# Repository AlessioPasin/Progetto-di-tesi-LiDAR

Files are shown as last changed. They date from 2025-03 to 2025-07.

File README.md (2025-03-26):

# Progetto di tesi: **Scheda per sensore LiDAR**

## Obiettivo:

Il seguente progetto riguarda una scheda per la gestione di due periferiche esterne: un laser ed un fotoricevitore.
L'obiettivo finale con la scheda è quello di realizzare un sensore LiDAR. Tale sensore viene utilizzato in diversi campi per misurare quella che è la distanza degli oggetti circostanti. Ne esistono di diverse tipologie e che sfruttano diversi principi fisici.

In questa applicazione viene utilizzato il **ToF** [*Time of Filght*], ossia il tempo che impiega il fascio laser per viaggare dalla sorgente all'oggetto e per poi tornare nuovamente alla fonte.

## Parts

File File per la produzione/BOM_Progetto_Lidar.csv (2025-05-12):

Source: | D:\Documenti_A\Università\Corsi\Tesi\Progetto Kicad Lidar\Progetto Lidar.kicad_sch
Date: | 12/05/2025 09:19:33
Tool: | Eeschema (6.0.10)
Generator: | C:\Program Files\KiCad\6.0\bin\scripting\plugins/bom_csv_grouped_by_value.py
Component Count: | 44
Individual Components:
Item | Qty | Reference(s) | Value | LibPart | Footprint | Datasheet | Datasheet_1 | Dettagli | Footprint_1 | Height | Manufacturer_Name | Manufacturer_Part_Number | Modello | Mouser Part Number | Mouser Price/Stock | Reference_1 | Value_1
 |  | C1 | 0.1uF | Device:C | Capacitor_SMD:C_0805_2012Metric | ~
 |  | C2 | 1uF | Device:C | Capacitor_SMD:C_0805_2012Metric | ~
 |  | C3 | 100nF | Device:C | Capacitor_SMD:C_0805_2012Metric | ~
 |  | C4 | 1uF | Device:C | Capacitor_SMD:C_0805_2012Metric | ~ |  | Ceramico con ESR: 100 mOhm max
 |  | C5 | 100nF | Device:C | Capacitor_SMD:C_0805_2012Metric | ~
 |  | C6 | 100nF | Device:C | Capacitor_SMD:C_0805_2012Metric | ~
 |  | C7 | 100nF | Device:C | Capacitor_SMD:C_0805_2012Metric | ~
 |  | C8 | 1nF | Device:C | Capacitor_SMD:C_0805_2012Metric | ~
 |  | C9 | 1nF | Device:C | Capacitor_SMD:C_0805_2012Metric | ~
 |  | C10 | 50pF | Device:C | Capacitor_SMD:C_0805_2012Metric | ~
 |  | C11 | 1nF | Device:C | Capacitor_SMD:C_0805_2012Metric | ~
 |  | C12 | 1nF | Device:C | Capacitor_SMD:C_0805_2012Metric | ~
 |  | D1 | 5V | Device:LED | LED_SMD:LED_0805_2012Metric | https://www.mouser.it/ProductDetail/ROHM-Semiconductor/SML-211UTT86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
 |  | D2 | 3V3 | Device:LED | LED_SMD:LED_0805_2012Metric | ~
 |  | D3 | D_Shockley | Device:D_Schottky | Libreria_componenti_footprint:RB511VM30TE17 | Datasheet/rb511vm-30te-17-e.pdf |  |  |  |  |  |  | RB511VM-30TE-17
 |  | IC_0 | Arduino_Due_Shield | arduino-library:Arduino_Due_Shield | arduino-library:Arduino_Due_Shield | https://docs.arduino.cc/hardware/due
 |  | IC_1 | TDC7200PW | Libreria_componenti:TDC7200PW | Libreria_componenti_footprint:SOP65P640X120-14N | Datasheet/tdc7200.pdf | http://www.ti.com/lit/ds/symlink/tdc7200.pdf |  | SOP65P640X120-14N | 1.2 | Texas Instruments | TDC7200PW |  | 595-TDC7200PW | https://www.mouser.co.uk/ProductDetail/Texas-Instruments/TDC7200PW?qs=Q2snjRlG%2FBIHkOu3cFqg1g%3D%3D | IC | TDC7200PW
 |  | IC_2 | SiT2024BA-S2-33E-8.000000G | Libreria_componenti:SiT2024BA-S2-33E-8.000000G | Libreria_componenti_footprint:SOT95P280X145-5N | Datasheet/SiT2024B.pdf | https://www.mouser.it/datasheet/2/371/SiT2024B-datasheet-1110818.pdf |  | SOT95P280X145-5N | 1.45 | SiTime | SiT2024BA-S2-33E-8.000000G |  | 788-2024BA-S2-33E-8G | https://www.mouser.co.uk/ProductDetail/SiTime/SiT2024BA-S2-33E-8.000000G?qs=dMZC7um9hO%2FirfxPzzDefA%3D%3D | Y | SiT2024BA-S2-33E-8.000000G
 |  | IC_3 | SN74LVC1G125DCKR | Libreria_componenti:SN74LVC1G125DCKR | Libreria_componenti_footprint:SOT65P210X110-5N | Datasheet/sn74lvc1g125.pdf | https://datasheet.datasheetarchive.com/originals/distributors/Datasheets-302/24053.pdf |  | SOT65P210X110-5N | 1.1 | Texas Instruments | SN74LVC1G125DCKR |  | 595-SN74LVC1G125DCKR | https://www.mouser.co.uk/ProductDetail/Texas-Instruments/SN74LVC1G125DCKR?qs=dT9u2OTAaVUrYF5qV08%2Fhw%3D%3D | IC | SN74LVC1G125DCKR
 |  | IC_4 | LT1719IS6#TRPBF | Libreria_componenti:LT1719IS6#TRPBF | Libreria_componenti_footprint:SOT95P280X100-6N | Datasheet/LT1719IS6.pdf | https://www.analog.com/media/en/technical-documentation/data-sheets/1719fa.pdf |  | SOT95P280X100-6N | 1 | Analog Devices | LT1719IS6#TRPBF |  | 584-LT1719IS6#TRPBF | https://www.mouser.co.uk/ProductDetail/Analog-Devices/LT1719IS6TRPBF?qs=ytflclh7QUW7a8zSEpHCoA%3D%3D | IC | LT1719IS6#TRPBF
 |  | IC_5 | TLV74133PDBVR | Libreria_componenti:TLV74133PDBVR | Libreria_componenti_footprint:SOT95P280X145-5N | Datasheet/tlv741p.pdf |  |  |  | 1.45 | Texas Instruments | TLV74133PDBVR |  | 595-TLV74133PDBVR | https://www.mouser.co.uk/ProductDetail/Texas-Instruments/TLV74133PDBVR?qs=EU6FO9ffTwd%252Bkie4AO1Iww%3D%3D
 |  | J1 | CONN_LASER | Connector:Conn_Coaxial | Connector_Coaxial:SMA_Molex_73251-1153_EdgeMount_Horizontal | ~
 |  | J2 | CONN_RICEVITORE | Connector:Conn_Coaxial | Connector_Coaxial:SMA_Molex_73251-1153_EdgeMount_Horizontal | ~
 |  | J3 | Conn_02x18_Odd_Even | Connector_Generic:Conn_02x18_Odd_Even | Connector_PinSocket_2.54mm:PinSocket_2x18_P2.54mm_Vertical | ~
 |  | J4 | Conn_01x10 | Connector_Generic:Conn_01x10 | Connector_PinSocket_2.54mm:PinSocket_1x10_P2.54mm_Vertical | ~
 |  | J5 | Conn_01x08 | Connector_Generic:Conn_01x08 | Connector_PinSocket_2.54mm:PinSocket_1x08_P2.54mm_Vertical | ~
 |  | J6 | Conn_01x08 | Connector_Generic:Conn_01x08 | Connector_PinSocket_2.54mm:PinSocket_1x08_P2.54mm_Vertical | ~
 |  | J7 | Conn_01x08 | Connector_Generic:Conn_01x08 | Connector_PinSocket_2.54mm:PinSocket_1x08_P2.54mm_Vertical | ~
 |  | J8 | Conn_SPI | Connector_Generic:Conn_02x03_Odd_Even | Connector_PinSocket_2.54mm:PinSocket_2x03_P2.54mm_Vertical | ~
 |  | J9 | Conn_01x08 | Connector_Generic:Conn_01x08 | Connector_PinSocket_2.54mm:PinSocket_1x08_P2.54mm_Vertical | ~
 |  | J10 | Conn_01x08 | Connector_Generic:Conn_01x08 | Connector_PinSocket_2.54mm:PinSocket_1x08_P2.54mm_Vertical | ~
 |  | JP1 | REG_EN | Jumper:SolderJumper_2_Open | Jumper:SolderJumper-2_P1.3mm_Open_RoundedPad1.0x1.5mm | ~
 |  | JP2 | LDO_EN | Jumper:SolderJumper_3_Open | Jumper:SolderJumper-3_P1.3mm_Open_Pad1.0x1.5mm_NumberLabels | ~
 |  | JP3 | OSC_EN | Jumper:SolderJumper_2_Open | Jumper:SolderJumper-2_P1.3mm_Open_RoundedPad1.0x1.5mm | ~
 |  | R1 | 10k | Device:R | Resistor_SMD:R_0805_2012Metric | ~
 |  | R2 | 1k8 | Device:R | Resistor_SMD:R_0805_2012Metric | ~
 |  | R3 | 820 | Device:R | Resistor_SMD:R_0805_2012Metric | ~
 |  | R4 | 47 | Device:R | Resistor_SMD:R_0805_2012Metric | ~
 |  | R5 | 180 | Device:R | Resistor_SMD:R_0805_2012Metric | ~
 |  | R6 | 100 | Device:R | Resistor_SMD:R_0805_2012Metric | ~
 |  | R7 | 100 | Device:R | Resistor_SMD:R_0805_2012Metric | ~
 |  | R8 | 100 | Device:R | Resistor_SMD:R_0805_2012Metric | ~
 |  | R9 | 100 | Device:R | Resistor_SMD:R_0805_2012Metric | ~
 |  | R10 | 100 | Device:R | Resistor_SMD:R_0805_2012Metric | ~
Collated Components:
Item | Qty | Reference(s) | Value | LibPart | Footprint | Datasheet | Datasheet_1 | Dettagli | Footprint_1 | Height | Manufacturer_Name | Manufacturer_Part_Number | Modello | Mouser Part Number | Mouser Price/Stock | Reference_1 | Value_1
1 | 1 | C1 | 0.1uF | Device:C | Capacitor_SMD:C_0805_2012Metric | ~
2 | 2 | C2, C4 | 1uF | Device:C | Capacitor_SMD:C_0805_2012Metric | ~ |  | Ceramico con ESR: 100 mOhm max
3 | 4 | C3, C5, C6, C7 | 100nF | Device:C | Capacitor_SMD:C_0805_2012Metric | ~
4 | 4 | C8, C9, C11, C12 | 1nF | Device:C | Capacitor_SMD:C_0805_2012Metric | ~
5 | 1 | C10 | 50pF | Device:C | Capacitor_SMD:C_0805_2012Metric | ~
6 | 1 | D1 | 5V | Device:LED | LED_SMD:LED_0805_2012Metric | https://www.mouser.it/ProductDetail/ROHM-Semiconductor/SML-211UTT86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
7 | 1 | D2 | 3V3 | Device:LED | LED_SMD:LED_0805_2012Metric | ~
8 | 1 | D3 | D_Shockley | Device:D_Schottky | Libreria_componenti_footprint:RB511VM30TE17 | Datasheet/rb511vm-30te-17-e.pdf |  |  |  |  |  |  | RB511VM-30TE-17
9 | 1 | IC_0 | Arduino_Due_Shield | arduino-library:Arduino_Due_Shield | arduino-library:Arduino_Due_Shield | https://docs.arduino.cc/hardware/due
10 | 1 | IC_1 | TDC7200PW | Libreria_componenti:TDC7200PW | Libreria_componenti_footprint:SOP65P640X120-14N | Datasheet/tdc7200.pdf | http://www.ti.com/lit/ds/symlink/tdc7200.pdf |  | SOP65P640X120-14N | 1.2 | Texas Instruments | TDC7200PW |  | 595-TDC7200PW | https://www.mouser.co.uk/ProductDetail/Texas-Instruments/TDC7200PW?qs=Q2snjRlG%2FBIHkOu3cFqg1g%3D%3D | IC | TDC7200PW
11 | 1 | IC_2 | SiT2024BA-S2-33E-8.000000G | Libreria_componenti:SiT2024BA-S2-33E-8.000000G | Libreria_componenti_footprint:SOT95P280X145-5N | Datasheet/SiT2024B.pdf | https://www.mouser.it/datasheet/2/371/SiT2024B-datasheet-1110818.pdf |  | SOT95P280X145-5N | 1.45 | SiTime | SiT2024BA-S2-33E-8.000000G |  | 788-2024BA-S2-33E-8G | https://www.mouser.co.uk/ProductDetail/SiTime/SiT2024BA-S2-33E-8.000000G?qs=dMZC7um9hO%2FirfxPzzDefA%3D%3D | Y | SiT2024BA-S2-33E-8.000000G
12 | 1 | IC_3 | SN74LVC1G125DCKR | Libreria_componenti:SN74LVC1G125DCKR | Libreria_componenti_footprint:SOT65P210X110-5N | Datasheet/sn74lvc1g125.pdf | https://datasheet.datasheetarchive.com/originals/distributors/Datasheets-302/24053.pdf |  | SOT65P210X110-5N | 1.1 | Texas Instruments | SN74LVC1G125DCKR |  | 595-SN74LVC1G125DCKR | https://www.mouser.co.uk/ProductDetail/Texas-Instruments/SN74LVC1G125DCKR?qs=dT9u2OTAaVUrYF5qV08%2Fhw%3D%3D | IC | SN74LVC1G125DCKR
13 | 1 | IC_4 | LT1719IS6#TRPBF | Libreria_componenti:LT1719IS6#TRPBF | Libreria_componenti_footprint:SOT95P280X100-6N | Datasheet/LT1719IS6.pdf | https://www.analog.com/media/en/technical-documentation/data-sheets/1719fa.pdf |  | SOT95P280X100-6N | 1 | Analog Devices | LT1719IS6#TRPBF |  | 584-LT1719IS6#TRPBF | https://www.mouser.co.uk/ProductDetail/Analog-Devices/LT1719IS6TRPBF?qs=ytflclh7QUW7a8zSEpHCoA%3D%3D | IC | LT1719IS6#TRPBF
14 | 1 | IC_5 | TLV74133PDBVR | Libreria_componenti:TLV74133PDBVR | Libreria_componenti_footprint:SOT95P280X145-5N | Datasheet/tlv741p.pdf |  |  |  | 1.45 | Texas Instruments | TLV74133PDBVR |  | 595-TLV74133PDBVR | https://www.mouser.co.uk/ProductDetail/Texas-Instruments/TLV74133PDBVR?qs=EU6FO9ffTwd%252Bkie4AO1Iww%3D%3D
15 | 1 | J1 | CONN_LASER | Connector:Conn_Coaxial | Connector_Coaxial:SMA_Molex_73251-1153_EdgeMount_Horizontal | ~
16 | 1 | J2 | CONN_RICEVITORE | Connector:Conn_Coaxial | Connector_Coaxial:SMA_Molex_73251-1153_EdgeMount_Horizontal | ~
17 | 1 | J3 | Conn_02x18_Odd_Even | Connector_Generic:Conn_02x18_Odd_Even | Connector_PinSocket_2.54mm:PinSocket_2x18_P2.54mm_Vertical | ~
18 | 1 | J4 | Conn_01x10 | Connector_Generic:Conn_01x10 | Connector_PinSocket_2.54mm:PinSocket_1x10_P2.54mm_Vertical | ~
19 | 5 | J5, J6, J7, J9, J10 | Conn_01x08 | Connector_Generic:Conn_01x08 | Connector_PinSocket_2.54mm:PinSocket_1x08_P2.54mm_Vertical | ~
20 | 1 | J8 | Conn_SPI | Connector_Generic:Conn_02x03_Odd_Even | Connector_PinSocket_2.54mm:PinSocket_2x03_P2.54mm_Vertical | ~
21 | 1 | JP1 | REG_EN | Jumper:SolderJumper_2_Open | Jumper:SolderJumper-2_P1.3mm_Open_RoundedPad1.0x1.5mm | ~
22 | 1 | JP2 | LDO_EN | Jumper:SolderJumper_3_Open | Jumper:SolderJumper-3_P1.3mm_Open_Pad1.0x1.5mm_NumberLabels | ~
23 | 1 | JP3 | OSC_EN | Jumper:SolderJumper_2_Open | Jumper:SolderJumper-2_P1.3mm_Open_RoundedPad1.0x1.5mm | ~
24 | 1 | R1 | 10k | Device:R | Resistor_SMD:R_0805_2012Metric | ~
25 | 1 | R2 | 1k8 | Device:R | Resistor_SMD:R_0805_2012Metric | ~
26 | 1 | R3 | 820 | Device:R | Resistor_SMD:R_0805_2012Metric | ~
27 | 1 | R4 | 47 | Device:R | Resistor_SMD:R_0805_2012Metric | ~
28 | 1 | R5 | 180 | Device:R | Resistor_SMD:R_0805_2012Metric | ~
29 | 5 | R6, R7, R8, R9, R10 | 100 | Device:R | Resistor_SMD:R_0805_2012Metric | ~

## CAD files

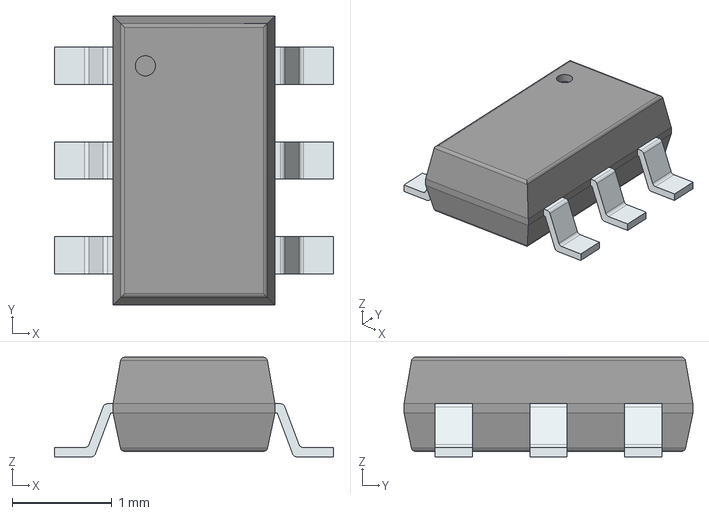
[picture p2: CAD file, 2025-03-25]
Componenti scaricati/LIB_LT1719IS6#TRPBF/3D/LT1719IS6#TRPBF.stp
2.80 x 2.90 x 1.00 mm
PinsArrayLR

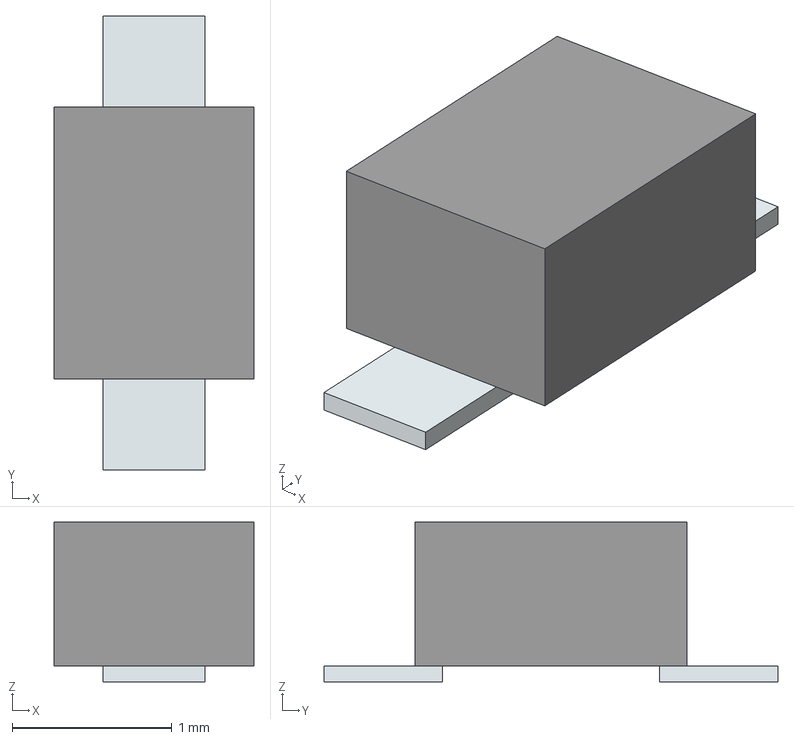
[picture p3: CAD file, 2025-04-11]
Componenti scaricati/LIB_RB511VM-30TE-17/3D/RB511VM-30TE-17.stp
1.25 x 2.84 x 1.00 mm
Pins

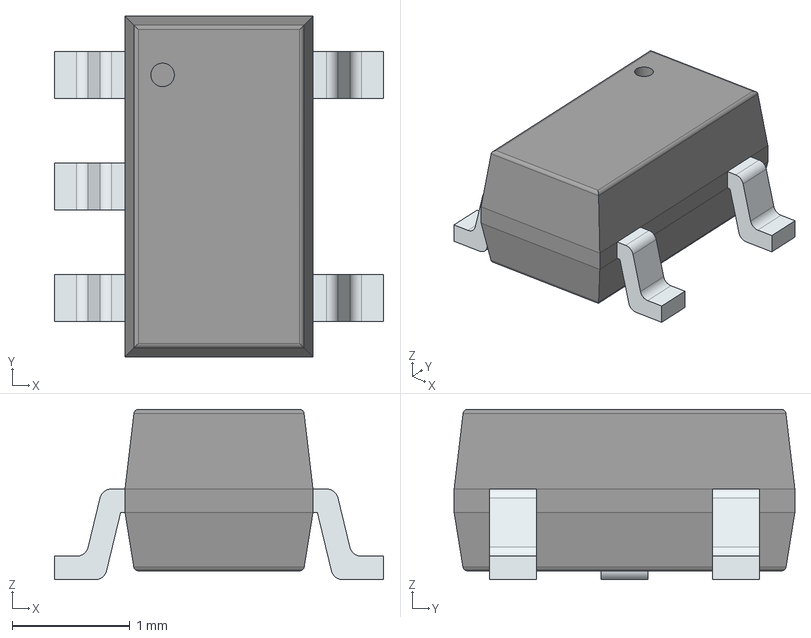
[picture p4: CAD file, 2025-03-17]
Componenti scaricati/LIB_SiT2024BA-S2-33E-8.000000G/3D/SiT2024BA-S2-33E-8.000000G.stp
2.80 x 2.90 x 1.45 mm
PinsArrayL
PinsArrayR

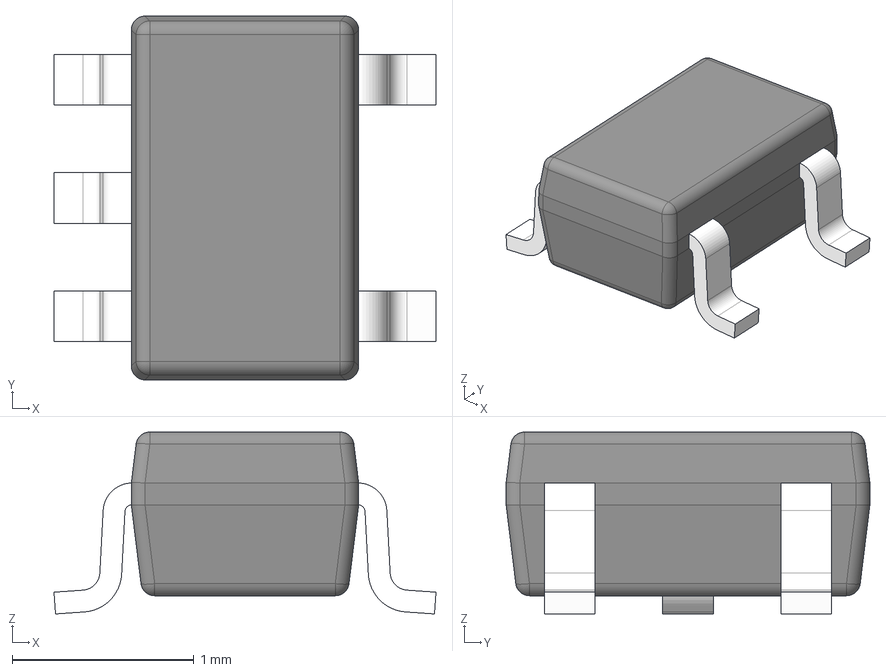
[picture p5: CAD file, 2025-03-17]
Componenti scaricati/LIB_SN74LVC1G125DCKR/3D/SN74LVC1G125DCKR.stp
2.10 x 2.00 x 1.00 mm
BODY-SOT
LEAD-SOT x 5
PIN1-ID

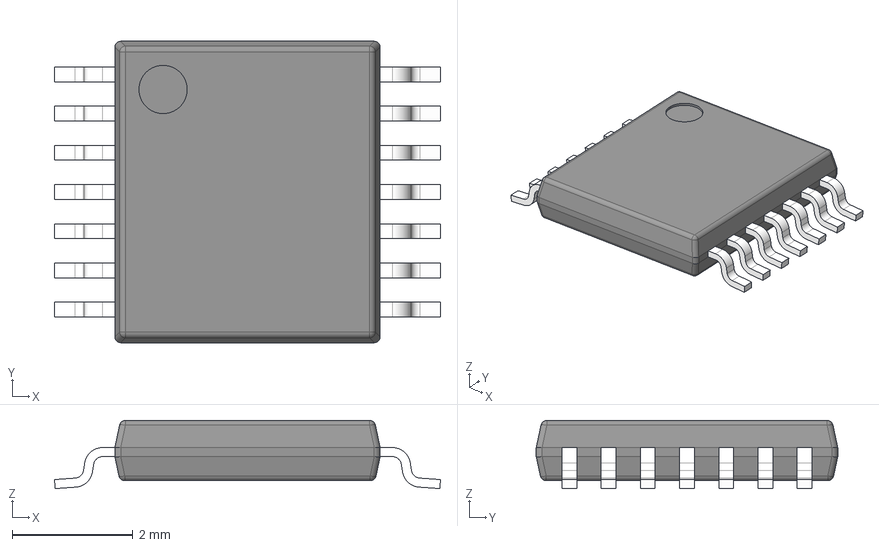
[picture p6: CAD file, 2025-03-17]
Componenti scaricati/LIB_TDC7200PW/3D/TDC7200PW.stp
6.40 x 5.00 x 1.13 mm
BODY-TSSOP
LEAD-TSSOP x 14
PIN1

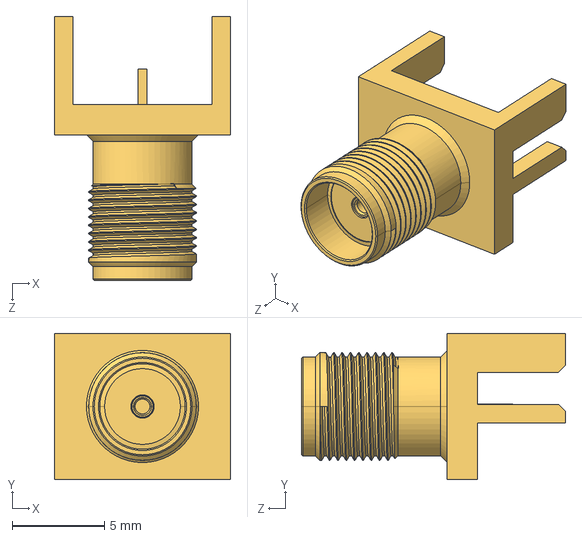
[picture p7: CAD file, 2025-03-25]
Componenti scaricati/2484637-1/3D/2484637-1.stp
9.53 x 7.92 x 14.3 mm

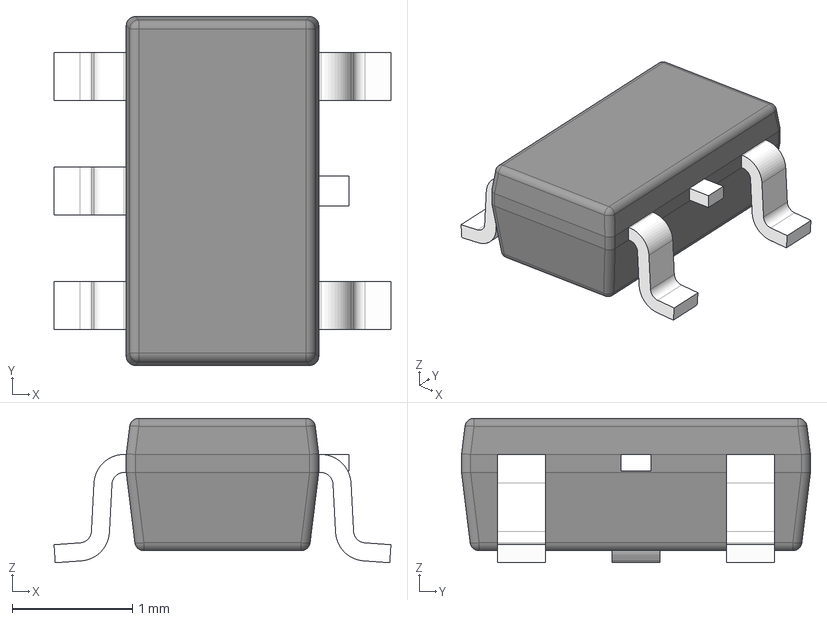
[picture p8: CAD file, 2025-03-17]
Componenti scaricati/LIB_TLV74133PDBVR/3D/TLV74133PDBVR.stp
2.80 x 2.90 x 1.20 mm
BODY-SOT
LEAD-SOT x 5
LEAD-DUMMY

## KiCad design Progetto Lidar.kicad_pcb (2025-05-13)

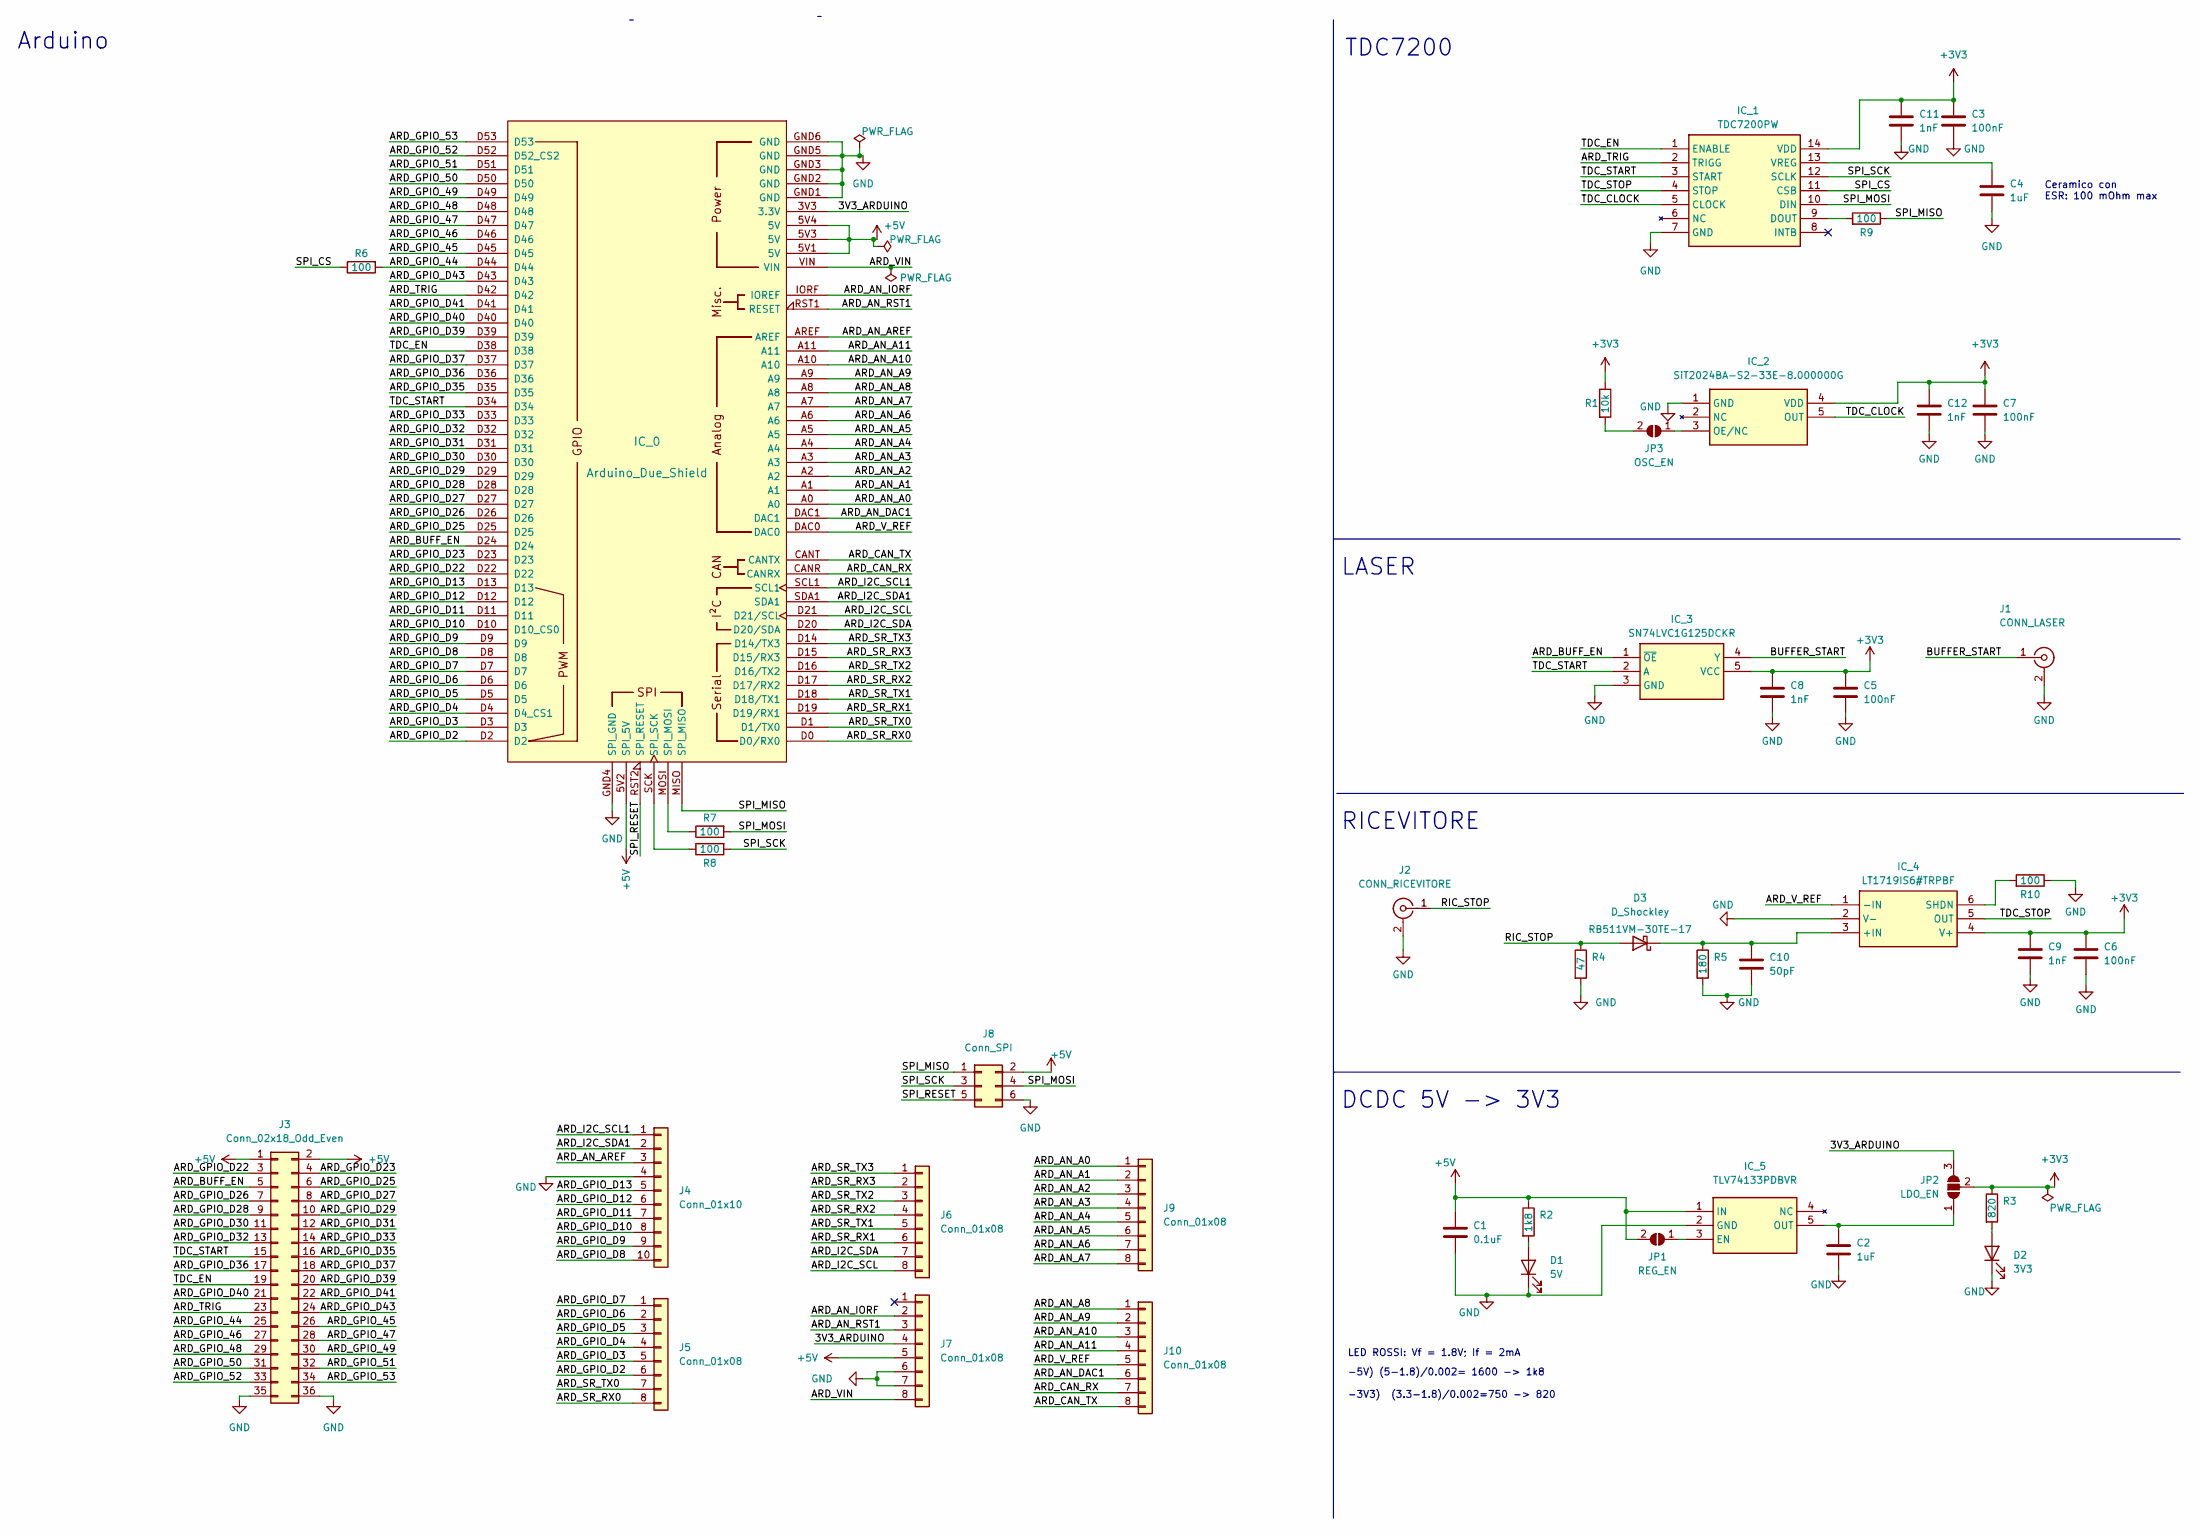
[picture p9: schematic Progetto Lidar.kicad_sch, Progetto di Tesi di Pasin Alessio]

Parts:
C1: 0.1uF; C_0805_2012Metric
C2, C4: 1uF; C_0805_2012Metric
C3, C5, C6, C7: 100nF; C_0805_2012Metric
C8, C9, C11, C12: 1nF; C_0805_2012Metric
C10: 50pF; C_0805_2012Metric
D1: 5V; LED_0805_2012Metric
D2: 3V3; LED_0805_2012Metric
D3: D_Shockley; RB511VM30TE17
IC_0: Arduino_Due_Shield
IC_1: TDC7200PW; SOP65P640X120-14N; Mouser Part Number 595-TDC7200PW
IC_2: SiT2024BA-S2-33E-8.000000G; SOT95P280X145-5N; Mouser Part Number 788-2024BA-S2-33E-8G
IC_3: SN74LVC1G125DCKR; SOT65P210X110-5N; Mouser Part Number 595-SN74LVC1G125DCKR
IC_4: LT1719IS6#TRPBF; SOT95P280X100-6N; Mouser Part Number 584-LT1719IS6#TRPBF
IC_5: TLV74133PDBVR; SOT95P280X145-5N; Mouser Part Number 595-TLV74133PDBVR
J1: CONN_LASER; SMA_Molex_73251-1153_EdgeMount_Horizontal
J2: CONN_RICEVITORE; SMA_Molex_73251-1153_EdgeMount_Horizontal
J3: Conn_02x18_Odd_Even; PinSocket_2x18_P2.54mm_Vertical
J4: Conn_01x10; PinSocket_1x10_P2.54mm_Vertical
J5, J6, J7, J9, J10: Conn_01x08; PinSocket_1x08_P2.54mm_Vertical
J8: Conn_SPI; PinSocket_2x03_P2.54mm_Vertical
JP1: REG_EN; SolderJumper-2_P1.3mm_Open_RoundedPad1.0x1.5mm
JP2: LDO_EN; SolderJumper-3_P1.3mm_Open_Pad1.0x1.5mm_NumberLabels
JP3: OSC_EN; SolderJumper-2_P1.3mm_Open_RoundedPad1.0x1.5mm
R1: 10k; R_0805_2012Metric
R2: 1k8; R_0805_2012Metric
R3: 820; R_0805_2012Metric
R4: 47; R_0805_2012Metric
R5: 180; R_0805_2012Metric
R6, R7, R8, R9, R10: 100; R_0805_2012Metric

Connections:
+3V3: C3.1, C5.1, C6.1, C7.1, C8.1, C9.1, C11.1, C12.1, IC_1.14 (VDD), IC_2.4 (VDD), IC_3.5 (VCC), IC_4.4 (V+), JP2.2 (C), R1.1, R3.1
+5V: C1.1, IC_0.5V1 (5V), IC_0.5V2 (SPI_5V), IC_0.5V3 (5V), IC_0.5V4 (5V), IC_5.1 (IN), J3.1, J3.2, J7.5, J8.2, JP1.2 (B), R2.1
/3V3_ARDUINO: IC_0.3V3 (3.3V), J7.4, JP2.3 (B)
/ARD_AN_A0: IC_0.A0, J9.1
/ARD_AN_A1: IC_0.A1, J9.2
/ARD_AN_A2: IC_0.A2, J9.3
/ARD_AN_A3: IC_0.A3, J9.4
/ARD_AN_A4: IC_0.A4, J9.5
/ARD_AN_A5: IC_0.A5, J9.6
/ARD_AN_A6: IC_0.A6, J9.7
/ARD_AN_A7: IC_0.A7, J9.8
/ARD_AN_A8: IC_0.A8, J10.1
/ARD_AN_A9: IC_0.A9, J10.2
/ARD_AN_A10: IC_0.A10, J10.3
/ARD_AN_A11: IC_0.A11, J10.4
/ARD_AN_AREF: IC_0.AREF, J4.3
/ARD_AN_DAC1: IC_0.DAC1, J10.6
/ARD_AN_IORF: IC_0.IORF (IOREF), J7.2
/ARD_AN_RST1: IC_0.RST1 (RESET), J7.3
/ARD_BUFF_EN: IC_0.D24, IC_3.1 (~OE), J3.5
/ARD_CAN_RX: IC_0.CANR (CANRX), J10.7
/ARD_CAN_TX: IC_0.CANT (CANTX), J10.8
/ARD_GPIO_44: IC_0.D44, J3.25, R6.2
/ARD_GPIO_45: IC_0.D45, J3.26
/ARD_GPIO_46: IC_0.D46, J3.27
/ARD_GPIO_47: IC_0.D47, J3.28
/ARD_GPIO_48: IC_0.D48, J3.29
/ARD_GPIO_49: IC_0.D49, J3.30
/ARD_GPIO_50: IC_0.D50, J3.31
/ARD_GPIO_51: IC_0.D51, J3.32
/ARD_GPIO_52: IC_0.D52 (D52_CS2), J3.33
/ARD_GPIO_53: IC_0.D53, J3.34
/ARD_GPIO_D2: IC_0.D2, J5.6
/ARD_GPIO_D3: IC_0.D3, J5.5
/ARD_GPIO_D4: IC_0.D4 (D4_CS1), J5.4
/ARD_GPIO_D5: IC_0.D5, J5.3
/ARD_GPIO_D6: IC_0.D6, J5.2
/ARD_GPIO_D7: IC_0.D7, J5.1
/ARD_GPIO_D8: IC_0.D8, J4.10
/ARD_GPIO_D9: IC_0.D9, J4.9
/ARD_GPIO_D10: IC_0.D10 (D10_CS0), J4.8
/ARD_GPIO_D11: IC_0.D11, J4.7
/ARD_GPIO_D12: IC_0.D12, J4.6
/ARD_GPIO_D13: IC_0.D13, J4.5
/ARD_GPIO_D22: IC_0.D22, J3.3
/ARD_GPIO_D23: IC_0.D23, J3.4
/ARD_GPIO_D25: IC_0.D25, J3.6
/ARD_GPIO_D26: IC_0.D26, J3.7
/ARD_GPIO_D27: IC_0.D27, J3.8
/ARD_GPIO_D28: IC_0.D28, J3.9
/ARD_GPIO_D29: IC_0.D29, J3.10
/ARD_GPIO_D30: IC_0.D30, J3.11
/ARD_GPIO_D31: IC_0.D31, J3.12
/ARD_GPIO_D32: IC_0.D32, J3.13
/ARD_GPIO_D33: IC_0.D33, J3.14
/ARD_GPIO_D35: IC_0.D35, J3.16
/ARD_GPIO_D36: IC_0.D36, J3.17
/ARD_GPIO_D37: IC_0.D37, J3.18
/ARD_GPIO_D39: IC_0.D39, J3.20
/ARD_GPIO_D40: IC_0.D40, J3.21
/ARD_GPIO_D41: IC_0.D41, J3.22
/ARD_GPIO_D43: IC_0.D43, J3.24
/ARD_I2C_SCL: IC_0.D21 (D21/SCL), J6.8
/ARD_I2C_SCL1: IC_0.SCL1, J4.1
/ARD_I2C_SDA: IC_0.D20 (D20/SDA), J6.7
/ARD_I2C_SDA1: IC_0.SDA1, J4.2
/ARD_SR_RX0: IC_0.D0 (D0/RX0), J5.8
/ARD_SR_RX1: IC_0.D19 (D19/RX1), J6.6
/ARD_SR_RX2: IC_0.D17 (D17/RX2), J6.4
/ARD_SR_RX3: IC_0.D15 (D15/RX3), J6.2
/ARD_SR_TX0: IC_0.D1 (D1/TX0), J5.7
/ARD_SR_TX1: IC_0.D18 (D18/TX1), J6.5
/ARD_SR_TX2: IC_0.D16 (D16/TX2), J6.3
/ARD_SR_TX3: IC_0.D14 (D14/TX3), J6.1
/ARD_TRIG: IC_0.D42, IC_1.2 (TRIGG), J3.23
/ARD_VIN: IC_0.VIN, J7.8
/ARD_V_REF: IC_0.DAC0, IC_4.1 (-IN), J10.5
/BUFFER_START: IC_3.4 (Y), J1.1 (In)
/RIC_STOP: D3.2 (A), J2.1 (In), R4.1
/SPI_CS: IC_1.11 (CSB), R6.1
/SPI_MISO: IC_0.MISO (SPI_MISO), J8.1, R9.1
/SPI_MOSI: IC_1.10 (DIN), J8.4, R7.2
/SPI_RESET: IC_0.RST2 (SPI_RESET), J8.5
/SPI_SCK: IC_1.12 (SCLK), J8.3, R8.2
/TDC_CLOCK: IC_1.5 (CLOCK), IC_2.5 (OUT)
/TDC_EN: IC_0.D38, IC_1.1 (ENABLE), J3.19
/TDC_START: IC_0.D34, IC_1.3 (START), IC_3.2 (A), J3.15
/TDC_STOP: IC_1.4 (STOP), IC_4.5 (OUT)
GND: C1.2, C2.2, C3.2, C4.2, C5.2, C6.2, C7.2, C8.2, C9.2, C10.2, C11.2, C12.2, D1.1 (K), D2.1 (K), IC_0.GND1 (GND), IC_0.GND2 (GND), IC_0.GND3 (GND), IC_0.GND4 (SPI_GND), IC_0.GND5 (GND), IC_0.GND6 (GND), IC_1.7 (GND), IC_2.1 (GND), IC_3.3 (GND), IC_4.2 (V-), IC_5.2 (GND), J1.2 (Ext), J2.2 (Ext), J3.35, J3.36, J4.4, J7.6, J7.7, J8.6, R4.2, R5.2, R10.1
unnamed: C2.1, IC_5.5 (OUT), JP2.1 (A)
unnamed: C4.1, IC_1.13 (VREG)
unnamed: C10.1, D3.1 (K), IC_4.3 (+IN), R5.1
unnamed: D1.2 (A), R2.2
unnamed: D2.2 (A), R3.2
unnamed: IC_0.MOSI (SPI_MOSI), R7.1
unnamed: IC_0.SCK (SPI_SCK), R8.1
unnamed: IC_1.9 (DOUT), R9.2
unnamed: IC_2.3 (OE/NC), JP3.1 (A)
unnamed: IC_4.6 (SHDN), R10.2
unnamed: IC_5.3 (EN), JP1.1 (A)
unnamed: JP3.2 (B), R1.2

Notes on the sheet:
RICEVITORE
-5V) (5-1.8)/0.002= 1600 -> 1k8 -3V3) (3.3-1.8)/0.002=750 -> 820
DCDC 5V -> 3V3
Arduino
LED ROSSI: Vf = 1.8V; If = 2mA
LASER
TDC7200
Ceramico con ESR: 100 mOhm max

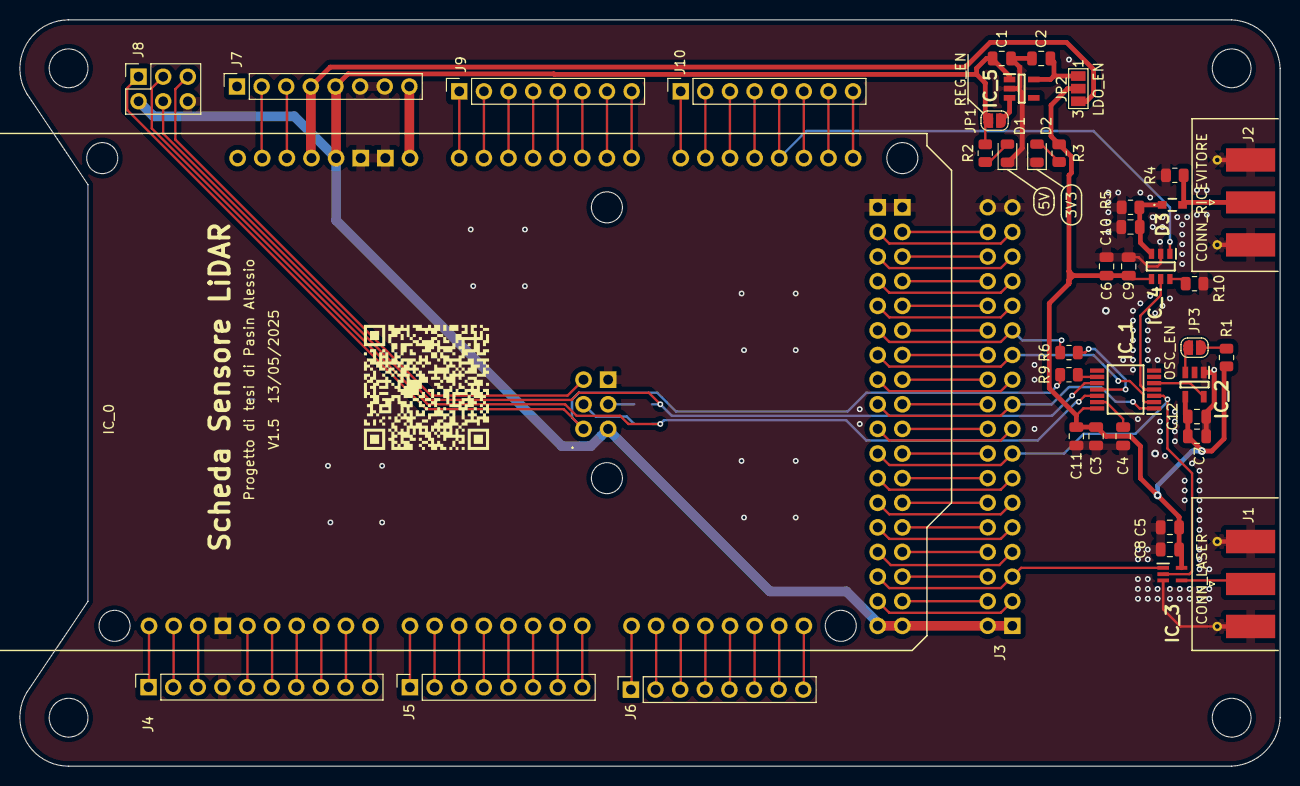
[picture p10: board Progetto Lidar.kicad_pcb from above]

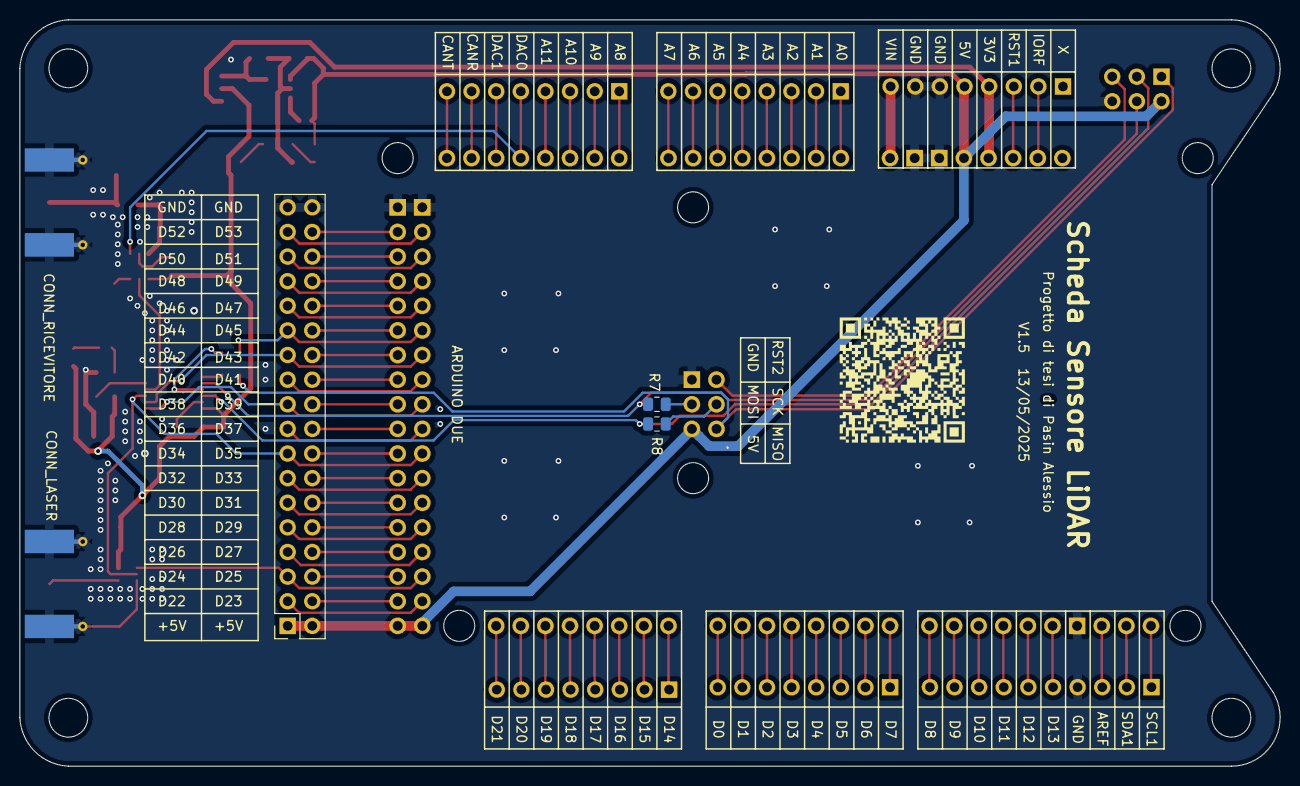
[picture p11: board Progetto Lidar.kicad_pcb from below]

Board: 2 copper layers, 130.0 x 77.0 mm, 44 parts (4 on the bottom side), 101 nets.

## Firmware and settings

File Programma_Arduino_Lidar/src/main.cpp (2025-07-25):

#include <Arduino.h>
#include <SPI.h>

//Definiamo alcune costanti che verranno utilizzate in seguito:

const int CS = 44;                //Pin di selezione del TDC. Viene utilizzato nella comunicazione SPI
const int TDC_EN = 38;            //Pin di ENABLE del TDC. Da inizializzare dopo l'accensione
const int ARD_TRIGG = 42;         //Pin di TRIGGER del TDC. Da inizializzare dopo l'accensione
const int TDC_START = 34;         //Pin di invio comando di partenza della misurazione
const int ARD_BUFF_EN = 24;       //Pin di ENABLE del BUFFER
const int ARD_V_REF = DAC0;       //Pin di generazione della tensione di riferimento
const int TDC_INTB = 48;       //Pin di generazione della tensione di riferimento

const int WRITE = 1;
const int READ = 0;

const int CalibPeriod = 10 ;    //Numero di cicli di calibrazione
const int ClockFreq = 8;        //Frequenza del clock in MHz (Noi in realtà avremmo 16MHz)
const double velLuce = 299792458.0 ; //Velocità espressa in m/s

int s = 0;                    // Variabile per la lettura dei registri di configurazione
int mod = 0;                    // Variabile di selezione del case del programma

unsigned int calib1 = 0b000000000000000000000000;        //Acquisiamo i valori
unsigned int calib2 = 0b000000000000000000000000;
unsigned int time1 = 0b000000000000000000000000;
unsigned int Clockcount1 = 0b000000000000000000000000;
unsigned int time2 = 0b000000000000000000000000;
unsigned int Clockcount2 = 0b000000000000000000000000;
unsigned int time3 = 0b000000000000000000000000;
long double calCount;
long double normLSB;
double TOF1;
double TOF2;
// double TOF3;
double TOF1nano;
double TOF2nano;
// double TOF3nano;
double distanza1;
double distanza2;
long double normLSBnano;



double boh;
double boh2;
//===========================================================================================================




void writeTDC(byte thisRegister, byte autoIncrement, byte thisValue)  //Si crea la funzione per l'invio dei dati dall'arduino al TDC:
{
  unsigned int sendDetails = (autoIncrement << 7) | (WRITE << 6) | (thisRegister) ; //Si crea il byte da 8 bit per il "Command field"
  // Serial.println(sendDetails, BIN);
  
  digitalWrite(CS, LOW);              //Si inizializza la fase di scrittura al dispositivo

  SPI.transfer(sendDetails);          //Si inviano le specifiche della comunicazione
  SPI.transfer(thisValue);            //Si invia il valore da inserire nel registro
  
  digitalWrite(CS, HIGH);             //Si termina la fase di scrittura al dispositivo
}




unsigned int readTDC(byte thisRegister, byte autoIncrement, int length)   //Si crea la funzione per la lettura dei dati con autoincremento dal TDC all'Arduino:
{
  if (length < 1 || length > 3) return 0;

  digitalWrite(CS, LOW);

  // Comando: [Auto-Inc][R/W][Addr(6 bit)]
  unsigned int command = (autoIncrement << 7) | (READ << 6) | (thisRegister);
  // Serial.println(command, BIN);
  SPI.transfer(command);


  // Legge i dati da MSB a LSB
  unsigned int value = 0b000000000000000000000000;
  for (int i = 0; i < length; i++) {
    value = (value << 8) | SPI.transfer(0x00);
    // Serial.println(value, BIN);
  }
  digitalWrite(CS, HIGH);
  return value;
}


void printDouble( double val, unsigned int precision){  //Funzione di stampa dei valori double

   Serial.print (int(val));  //prints the int part
    Serial.print("."); // print the decimal point
    unsigned int frac;
    if(val >= 0)
      frac = (val - int(val)) * precision;
    else
       frac = (int(val)- val ) * precision;
    int frac1 = frac;
    while( frac1 /= 10 )
        precision /= 10;
    precision /= 10;
    while(  precision /= 10)
        Serial.print("0");

    Serial.println(frac,DEC) ;
} 


//===============================================================================================================






void setup() {
  SPI.begin();
  SPI.beginTransaction(SPISettings(14000000, MSBFIRST, SPI_MODE0));
  Serial.begin(115200);
  Serial.println("Comunicazione inizializzata.");


  pinMode(CS, OUTPUT);                //Inizializziamo tutti i pin secondo la loro funzione
  pinMode(TDC_EN, OUTPUT);
  pinMode(ARD_TRIGG, INPUT);
  pinMode(TDC_START, OUTPUT);
  pinMode(ARD_BUFF_EN, OUTPUT);
  pinMode(ARD_V_REF, OUTPUT);
  pinMode(TDC_INTB, INPUT);
  
  
  
  digitalWrite(TDC_EN, LOW);               //Abilitiamo il TDC
  digitalWrite(ARD_BUFF_EN, HIGH);          //Imponiamo l'uscita in alta impedenza
  analogWrite(ARD_V_REF, 15);    //Impostiamo una tensione di riferimento da 0.1V
  
  delay(1500);
}



void loop() { //Costruiamo un programma basato sulla funzione switch-case: [0]=Solo lettura registri; [1]=Mod. misurazione 1; [2]=Mod. misurazione 2;
  
  mod=Serial.read(); 
  switch (mod)
{
  
  case '1':
  
  digitalWrite(TDC_EN, HIGH);               //Abilitiamo il TDC
  delay(100);
  Serial.println("=====<MODALITA' DI MISURAZIONE: 1 >======");       
  digitalWrite(ARD_BUFF_EN, LOW);         //Abilitiamo l'uscita del buffer
  Serial.println("Scrivo i registri di configurazione:");
  writeTDC(0x00, 0, 0b10000001);        //Definiamo i parametri del primo registro come: 01000000 (Pag: 25 datasheet)
  writeTDC(0x01, 0, 0b01000000);        //Definiamo i parametri del secondo registro come: 01000001 (Pag: 26 datasheet)
  
  delay(50);
  
  digitalWrite(13, LOW);
  Serial.println("<ESEGUO LA MISURAZIONE>");
  digitalWrite(TDC_START, HIGH);
  delay(1);
  digitalWrite(TDC_START, LOW);  
  delay(500);
  
  
  calib1 = readTDC(0x1B, 1, 3);        //Acquisiamo i valori
  calib2 = readTDC(0x1C, 1, 3);
  time1 = readTDC(0x10, 1, 3);
  
  
  calCount = (double(calib2 - calib1))/(CalibPeriod - 1) ;
  Serial.print("CalCount:");
  printDouble(calCount,10000);
  normLSB = ((1.0/double((ClockFreq *pow(10,6)))) * (1.0/calCount));
  normLSBnano = (normLSB*pow(10,11));
  Serial.print("normLSBnano1:");
  printDouble(normLSBnano,100);
  
  TOF1 = int(time1) * normLSB;
  TOF1nano = TOF1 * pow(10,9);
  Serial.print("TOF1 [ns]:");
  printDouble(TOF1nano,100);
  
  distanza1 = (velLuce * TOF1)/2 ; 
  Serial.print("Distanza1 [m]:");
  printDouble(distanza1,100);
  // digitalWrite(TDC_EN, LOW);               //Abilitiamo il TDC
  // delay(100);
  digitalWrite(13, HIGH);
  Serial.println("================================================");
  break;
  
  
  
  
  
  case '2':
  
  digitalWrite(TDC_EN, HIGH);               //Abilitiamo il TDC
  delay(100);
  Serial.println("=====<MODALITA' DI MISURAZIONE: 2 >======");       
  digitalWrite(ARD_BUFF_EN, LOW);         //Abilitiamo l'uscita del buffer
  Serial.println("Scrivo i registri di configurazione:");
  writeTDC(0x00, 0, 0b10000011);        //Definiamo i parametri del primo registro come: 01000000 (Pag: 25 datasheet)
  writeTDC(0x01, 0, 0b01000010);        //Definiamo i parametri del secondo registro come: 01000001 (Pag: 26 datasheet)
  
  delay(50);
  
  digitalWrite(13, LOW);
  Serial.println("<ESEGUO LA MISURAZIONE>");
  digitalWrite(TDC_START, HIGH);
  delay(1);
  digitalWrite(TDC_START, LOW);  
  delay(10);
  digitalWrite(TDC_START, HIGH);
  delay(1);
  digitalWrite(TDC_START, LOW);  
  delay(500);
  
  
  calib1 = readTDC(0x1B, 1, 3);        //Acquisiamo i valori
  calib2 = readTDC(0x1C, 1, 3);
  time1 = readTDC(0x10, 1, 3);
  Clockcount1 = readTDC(0x11, 1, 3);
  time2 = readTDC(0x12, 1, 3);
  Clockcount2 = readTDC(0x13, 1, 3);
  time3 = readTDC(0x14, 1, 3);
  
  
  calCount = (double(calib2 - calib1))/(CalibPeriod - 1) ;
  Serial.print("CalCount:");
  printDouble(calCount,10000);
  normLSB = ((1.0/double((ClockFreq *pow(10,6)))) * (1.0/calCount));
  normLSBnano = (normLSB*pow(10,11));
  Serial.print("normLSBnano:");
  printDouble(normLSBnano,100);


  TOF1 = normLSB*(int(time1)-int(time2) ) + (Clockcount1 * ((1.0/double((ClockFreq *pow(10,6))))));
  TOF2 = normLSB*(int(time1)-int(time3) ) + (Clockcount2 * ((1.0/double((ClockFreq *pow(10,6))))));

  TOF1nano = (TOF1 * pow(10,9));      //CORRETTO: Tempo espresso in nanosecondi [ns]
  TOF2nano = (TOF2 * pow(10,9));      //CORRETTO: Tempo espresso in nanosecondi [ns]
  // TOF3nano = (TOF3 * pow(10,9));      //CORRETTO: Tempo espresso in nanosecondi [ns]
  Serial.print("TOF1 [ns]:");
  printDouble(TOF1nano,100);
  Serial.print("TOF2 [ns]:");
  printDouble(TOF2nano,100);
  // Serial.print("TOF3 [ns]:");
  // printDouble(TOF3nano,100);
  
  distanza1 = (velLuce * TOF1)/2 ;
  distanza2 = (velLuce * TOF2)/2 ;
  Serial.print("Distanza1 [m]:");
  printDouble(distanza1,100);
  Serial.print("Distanza2 [m]:");
  printDouble(distanza2,100);
  // digitalWrite(TDC_EN, LOW);               //Abilitiamo il TDC
  // delay(100);
  digitalWrite(13, HIGH);
  Serial.println("================================================");
  break;
  
  
  
  default:
  
  digitalWrite(TDC_EN, HIGH);               //Abilitiamo il TDC
  delay(100);
  Serial.println("=====CALIBRATION1======");
  calib1 = readTDC(0x1B, 1, 3);
  Serial.print("Valore del calibration 1:");
  Serial.println(calib1, BIN);
  Serial.println(calib1, DEC);
  
  Serial.println("=====CALIBRATION2======");
  calib2 = readTDC(0x1C, 1, 3);
  Serial.print("Valore del calibration 2:");
  Serial.println(calib2, BIN);
  Serial.println(calib2, DEC);
  
  Serial.println("=====TIME 1======");
  time1 = readTDC(0x10, 1, 3);
  Serial.print("Valore del registro TIME 1:");
  Serial.println(time1, BIN);
  Serial.println(time1, DEC);
  
  Serial.println("=====CLOCK COUNT 1======");
  Clockcount1 = readTDC(0x11, 1, 3);
  Serial.print("Valore del registro CLOCK COUNT 1:");
  Serial.println(Clockcount1, BIN);
  Serial.println(Clockcount1, DEC);
  
  Serial.println("=====TIME 2======");
  time2 = readTDC(0x12, 1, 3);
  Serial.print("Valore del registro TIME 2:");
  Serial.println(time2, BIN);
  Serial.println(time2, DEC);
  
  Serial.println("=====CLOCK COUNT 2======");
  Clockcount2 = readTDC(0x13, 1, 3);
  Serial.print("Valore del registro CLOCK COUNT 2:");
  Serial.println(Clockcount2, BIN);
  Serial.println(Clockcount2, DEC);

  // Serial.println("=====TIME 3======");
  // time3 = readTDC(0x14, 1, 3);
  // Serial.print("Valore del registro TIME 2:");
  // Serial.println(time3, BIN);
  // Serial.println(time3, DEC);
  
  // Serial.println("=====<INT STATUS>======");
  // time3 = readTDC(0x02, 1, 1);
  // Serial.print("Configurazione registro INT STATUS:");
  // Serial.println(time3, BIN);


  digitalWrite(TDC_EN, LOW);               //Abilitiamo il TDC
  delay(100);
  break;
}

delay(4000);
}

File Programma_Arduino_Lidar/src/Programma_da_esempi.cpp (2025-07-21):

#include <Arduino.h>
#include <SPI.h>
#include <math.h>

//Definiamo alcune costanti che verranno utilizzate in seguito:

const double velLuce = 299792458.0 ; //Velocità espressa in m/s

//Definiamo dei valori pari a quelli che dovremmo ottenere dai registri del TDC. Si considerano gli esempi forniti dal datasheet:

int Calib1byte[3] = {0b00000000, 0b00001000, 0b00111110} ;    //LSB

int Calib2byte[3] = {0b00000000, 0b01010010, 0b10000001} ;    //LSB

int Time1byte[3] = {0b00000000, 0b00010000, 0b01001111} ;    //LSB




int Calib1byte2[3] = {0b00000000, 0b00001001, 0b00001011} ;    //LSB

int Calib2byte2[3] = {0b00000000, 0b01011010, 0b01011101} ;    //LSB

int Time1byte2[3] = {0b00000000, 0b00001000, 0b01100011} ;    //LSB

int Time2byte2[3] = {0b00000000, 0b00000000, 0b11001001} ;    //LSB

int ClockCount1byte2[3] = {0b00000000, 0b00000001, 0b00111110} ;    //LSB

const int CalibPeriod = 10 ;    //Numero di cicli di calibrazione

const int ClockFreq = 8;        //Frequenza del clock in MHz (Noi in realtà avremmo 16MHz)


//===============================================================================================================
//DUMMY FUNCTIONs, solo per creare la funzione di riferimento:

unsigned int readTDC(int valore[], int length)
{
  if (length < 1 || length > 3) return 0;
  
  // Legge i dati da MSB a LSB
  unsigned int value = 0b000000000000000000000000;
  for (int i = 0; i < length; i++) {
      value = (value << (8)) | valore[i];
    }
  return value;
}



void printDouble( double val, unsigned int precision){  //Funzione di stampa dei valori double

   Serial.print (int(val));  //prints the int part
    Serial.print("."); // print the decimal point
    unsigned int frac;
    if(val >= 0)
      frac = (val - int(val)) * precision;
    else
       frac = (int(val)- val ) * precision;
    int frac1 = frac;
    while( frac1 /= 10 )
        precision /= 10;
    precision /= 10;
    while(  precision /= 10)
        Serial.print("0");

    Serial.println(frac,DEC) ;
} 









void setup() {
  SPI.begin();
  SPI.beginTransaction(SPISettings(14000000, MSBFIRST, SPI_MODE0));
  Serial.begin(115200);  
  Serial.println("Comunicazione inizializzata.");
  pinMode(13, OUTPUT);


  Serial.print("CALIB 1:");
  unsigned int calibrazione1 = readTDC(Calib1byte, 3);
  Serial.println(calibrazione1);

  Serial.print("CALIB 2:");
  unsigned int calibrazione2 = readTDC(Calib2byte, 3);
  Serial.println(calibrazione2);
  
  Serial.print("TIME 1:");
  unsigned int time1 = readTDC(Time1byte, 3);
  Serial.println(time1);
  
  
  
  /*=====PRIMA MODALITA' DI FUNZIONAMENTO======*/
  
  long double calCount = (double(calibrazione2 - calibrazione1))/(CalibPeriod - 1) ;
  Serial.print("CalCount1:");
  printDouble(calCount,10000);
  
  // Serial.println(ClockFreq *pow(10.0,6.0));
  long double normLSB = ((1.0/double((ClockFreq *pow(10,6)))) * (1.0/calCount));
  long double normLSBnano = ((1.0/double((ClockFreq *pow(10,6)))) * (1.0/calCount)*pow(10,9));
  Serial.print("normLSBnano1:");
  printDouble(normLSBnano,100);
  
  double TOF1 = time1 * normLSB;
  double TOF1nano = time1 * normLSB * pow(10,9);      //CORRETTO: Tempo espresso in nanosecondi [ns]
  Serial.print("TOF1nano [us]:");
  printDouble(TOF1nano,100);
  
  double distanza = (velLuce * TOF1)/2 ; 
  Serial.print("Distanza1 [m]:");
  printDouble(distanza,100);
  
  
  
  
  Serial.println("====================== MODALITA' DUE ==========================");
  
  
  
  Serial.print("CALIB 1:");
  unsigned int calibrazione12 = readTDC(Calib1byte2, 3);
  Serial.println(calibrazione12);

  Serial.print("CALIB 2:");
  unsigned int calibrazione22 = readTDC(Calib2byte2, 3);
  Serial.println(calibrazione22);
  
  Serial.print("TIME 1:");
  unsigned int time12 = readTDC(Time1byte2, 3);
  Serial.println(time12);
  
  Serial.print("TIME 2:");
  unsigned int time22 = readTDC(Time2byte2, 3);
  Serial.println(time22);
  
  Serial.print("CLOCK_COUNT1:");
  unsigned int Clockcount1 = readTDC(ClockCount1byte2, 3);
  Serial.println(Clockcount1);


  Serial.println("================================================");   //Abbiamo costruito correttamente i valori di riferimento





  /*=====SECONDA MODALITA' DI FUNZIONAMENTO======*/

  long double calCount2 = (double(calibrazione22 - calibrazione12))/(CalibPeriod - 1) ;
  Serial.print("CalCount2:");
  printDouble(calCount2,10000);
  
  // Serial.println(ClockFreq *pow(10.0,6.0));
  long double normLSB2 = ((1.0/double((ClockFreq *pow(10,6)))) * (1.0/calCount2));
  long double normLSBnano2 = ((1.0/double((ClockFreq *pow(10,6)))) * (1.0/calCount2)*pow(10,12));
  Serial.print("normLSBpico:");
  printDouble(normLSBnano2,100);
  
  double TOF12 = (time12 * normLSB2) + (Clockcount1 * ((1.0/double((ClockFreq *pow(10,6)))))) - (time22 * normLSB2);
  double TOF12nano = (TOF12 * pow(10,6));      //CORRETTO: Tempo espresso in nanosecondi [ns]
  Serial.print("TOF2micro [us]:");
  printDouble(TOF12nano,100);
  
  double distanza2 = (velLuce * TOF12)/2 ;
  Serial.print("Distanza2 [m]:");
  printDouble(distanza2,100);

  delay(1500);
}



void loop() {

  digitalWrite(13, HIGH);
  delay(1000);
  digitalWrite(13, LOW);
  delay(1000);
}

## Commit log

2025-03-17 Primo commit con lo schematico quasi completato
    [LM393BIDR.stp, Progetto Lidar.kicad_pcb, Progetto Lidar.kicad_sch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]
2025-03-17 Finito lo schematico e aggiunto modelli 3D
    [73171-3150.stp, Progetto Lidar.kicad_pcb, Progetto Lidar.kicad_sch]
2025-03-19 Finito il layout della prima versione della scheda
    [Progetto Lidar.kicad_pcb, Progetto Lidar.kicad_sch]
2025-03-20 Specchiato Arduino per funzionare con connettori femmina
    [Progetto Lidar.kicad_pcb, Progetto Lidar.kicad_sch]
2025-03-25 Apportate modifiche dopo incontro con prof. 25.03.2025
    [2484637-1.stp, 73171-3150.stp, LM393BIDR.stp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]
2025-03-25 Finito layout e schematico. Aggiornato Silkscreen
    [Progetto Lidar.kicad_pcb, Progetto Lidar.kicad_sch]
2025-03-26 Aggiunto pinou di Arduino su silkscreen
    [Progetto Lidar.kicad_pcb, Progetto Lidar.kicad_sch]
2025-03-26 Modificato il Readme
2025-04-11 Corretto simulazione, aggiunto circuito di condizionamento del segnale e modificato il layout
    [Progetto Lidar.kicad_pcb, Progetto Lidar.kicad_sch, RB511VM-30TE-17.stp]
2025-04-13 Sistemato alcuni errori di circuito, aggiunto resistenze per SPI, aggiunto condensatori di filtraggio
    [Progetto Lidar.kicad_pcb, Progetto Lidar.kicad_sch]
2025-04-15 Ulteriori modifiche
    [Progetto Lidar.kicad_pcb]
2025-04-27 Corretto collegamento TDC_START
    [Progetto Lidar.kicad_pcb, Progetto Lidar.kicad_sch]
2025-05-12 Aggiunto vias nei circuiti veloci, rimosso piste GND, organizzato cartella e file, generato i file per la produzione
    [BOM_Progetto_Lidar.csv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]
2025-05-12 Sistemato file BOM
2025-05-12 Sistemata la BOM
2025-05-13 Corretto connessione TDC ENABLE
    [Progetto Lidar.kicad_pcb, Progetto Lidar.kicad_sch]
2025-05-13 Rifatti i file per la produzione, modificato diametro fori, aggiunto scritte sul retro
    [Progetto Lidar-B_Cu.gbl, Progetto Lidar-B_Mask.gbs, Progetto Lidar-B_Paste.gbp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]
2025-07-18 Aggiunta programma per Arduino
2025-07-18 Ulteriori modifiche. Bisogna verificare il funzionamento dell'oscillatore
    [main.cpp]
2025-07-21 Creato funzioni di conversione utilizzando gli esempi forniti dal datasheet
2025-07-21 Realizzato il codice per la conversione dai valori nel registro ad un effettivo valore in metri, sempre sfruttando gli esempi del datasheet
2025-07-21 Corretto file principale per la lettura dei registri del TDC
2025-07-24 Programma sviluppato secondo switch-case, funzionante e testato
2025-07-25 Versione corretta del programma. Era sbagliata la formula per il calcolo del TOF durante la seconda modalità di misurazione
